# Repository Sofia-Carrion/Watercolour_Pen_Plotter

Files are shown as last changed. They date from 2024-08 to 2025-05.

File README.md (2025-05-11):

# Watercolour_Pen_Plotter
(WIP)

<p align="center">
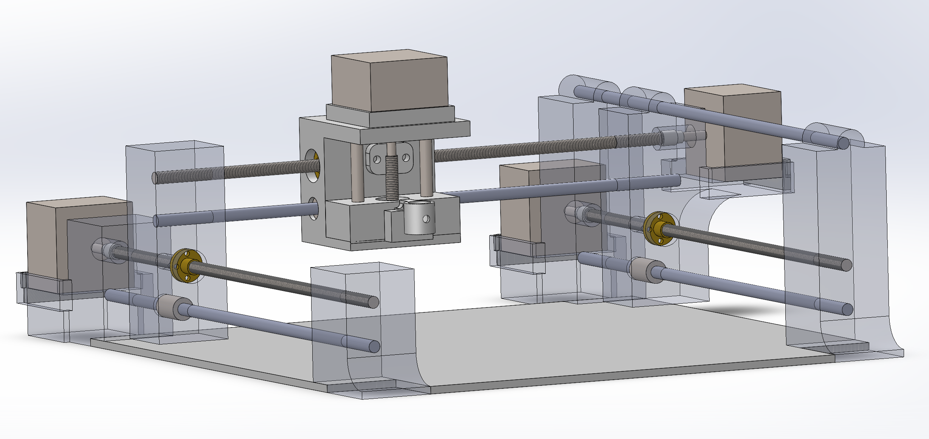
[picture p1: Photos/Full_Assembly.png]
Full Assembly
  
</p>

## About:
The Watercolour Pen Plotter is a CNC machine designed to operate like a traditional pen plotter but tailored for watercolor painting on traditional 8.5 x 11 paper. The goal is to create a compact, user-friendly frame with an added feature for mixing paint. The CNC machine will paint freely, blending colors and adjusting shades by varying the paint-to-water ratios through an automated process.

## Progress:
 [A detailed file describing the process can be found here](Progress.md)

Summary: 
_________________________________________________________________________________________________________________
Design:
- All components for the CNC machine have been brainstormed and designed. This was mainly done through sketches.
  
CAD:
- All CAD work has been completed for the chassis of the CNC machine on Solidworks. 

Electronics:
- Setup and tested scrap stepper motors that was found from an old machine by running G-code on CNC shield and Arduino Uno.

Prototyping:
- All custom parts have been printed and the chassis has been assmebled with the purchased metal parts.

Work to be complete:
- Running all electrical components with chassis: testing and debugging
- Research on how to manipulate G-code to preform painting
___________________________________________________________________________________________________________________

  The design process encompassed many sketches. A full PDF of my sketches can be found 
  [here](WCPP_Design.pdf)

## CAD Models:

All SolidWork CAD models were created using SolidWorks 2023. All files for the assembly can be found in the repository.

## External Help (Parts that will be put to use):

The following parts and links are pieces that I plan to use in this project. I used their dimensions to help create my CADs.

[Linear Ball Bearings](https://www.amazon.ca/Linear-Bearing-Bushing-Bearings-Printer/dp/B07G959TX9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 )

[Thread/Brass Nut](https://www.amazon.ca/150mm%EF%BC%885-9-Inches%EF%BC%89Tr8x2-Thread-Printer-Machine/dp/B08JLHSHQ7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)

[Metal Rods](https://www.amazon.ca/dp/B0BRKD43TP?ref=ppx_yo2ov_dt_b_fed_asin_title&th=1 )

Stepper Motors: (Not sure right now, they were scrap motors)

(Any other parts I will update as I move along)

  ## Looking to Help Out?

If you are interested in collaborating to make this project even bigger and cooler, don't hesitate to reach out! I'd love to work with others and get different insights and perspectives.

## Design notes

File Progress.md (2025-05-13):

# Current Progress

  ## WORK DONE FOR BASIC CHASSIS:
  ----------------------------------

  The project started off as a basic pen plotter. The following showcases the main steps I took to create a full SolidWorks assembly of its structure.

### 1. Movement:

  I began this project by planning the movement of the pen. Since the machine needed to draw, incorporating both the x and y axes was obvious. Likewise, adding a z-axis to lift and lower the pen onto the paper was essential. However, I needed to consider the displacement required for each axis. To keep things simple, I decided the machine should be capable of drawing anywhere on a standard 8.5 by 11-inch sheet of paper. For the z-axis, I chose a 1 cm range, which would provide enough clearance for brushes to create varying thicknesses if I decided to include that feature.
    
  With the basic concept established, I considered different ways to achieve movement. Having previous experience with CNC machines and having designed parts for one myself, I opted for a standard thread and nut, as my experience with these has been straightforward and reliable. Keeping this in mind, I started sketching how I envisioned the machine operating. An early-stage sketch can be seen below:

<p align="center">
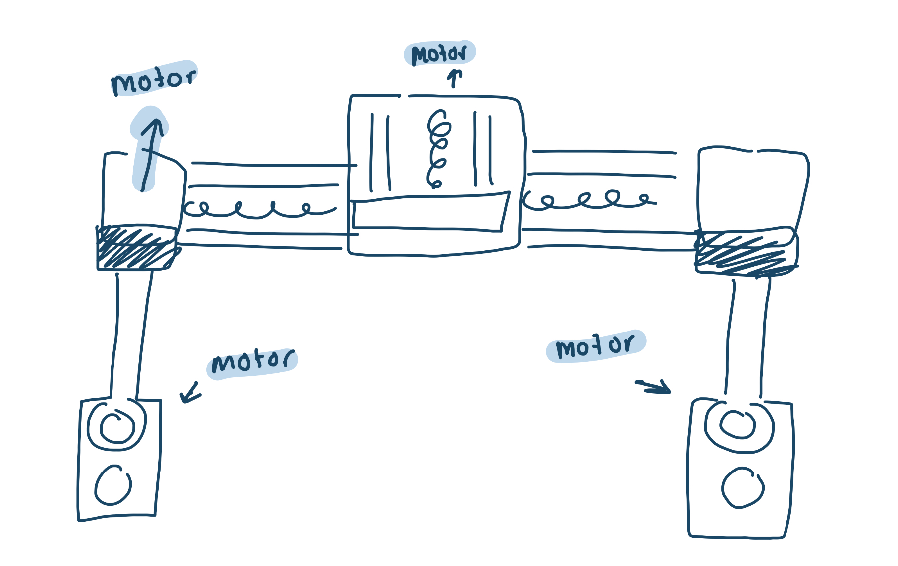
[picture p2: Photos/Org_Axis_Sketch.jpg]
Original Sketch
  
</p>

  Later on, I updated these sketches to be a bit more clear and showcase each axis individually:

<p align="center">
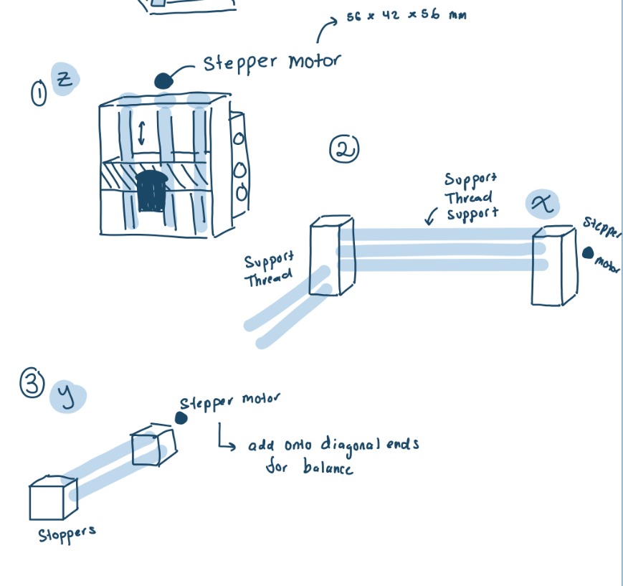
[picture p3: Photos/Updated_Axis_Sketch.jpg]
Updated Sketch
  
</p>

The general idea was that each axis would be controlled by 1-2 stepper motors, be moved through thread and nuts, and have two support beams to keep them in place. Additionally, linear ball bearings will be used where necessary to help facilitate movement.

### 2. Design of each axis:

  With a general idea of how I wanted the machine to operate, I began to do some work in CAD and assemble each of the axis individually. I played around with different sizes and shapes, aiming to make the machine as small as possible. The biggest change between the initial sketches and their new CADS was the removal of one of the support rods. This was done as I had found that everything was relatively light enough that one support rod could suffice (I did add an extra one for the right side of the y axis since the stepper motor would weight it down on one side). CADs of each assembly for the Z,X, and Y axis could be seen below:

<p align="center">
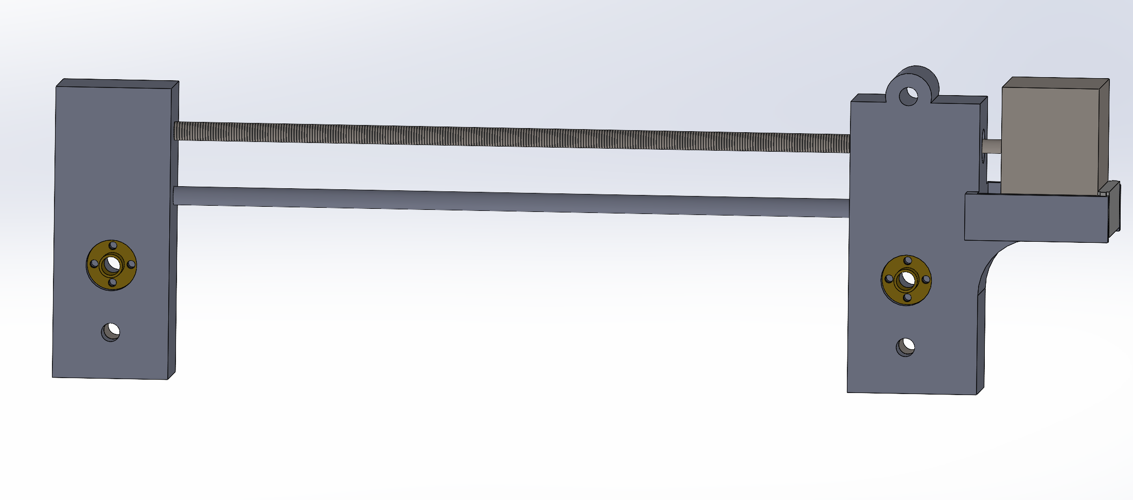
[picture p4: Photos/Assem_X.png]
CAD_x
  
</p>

<p align="center">
  Assembly of the X axis
</p>

<p align="center">
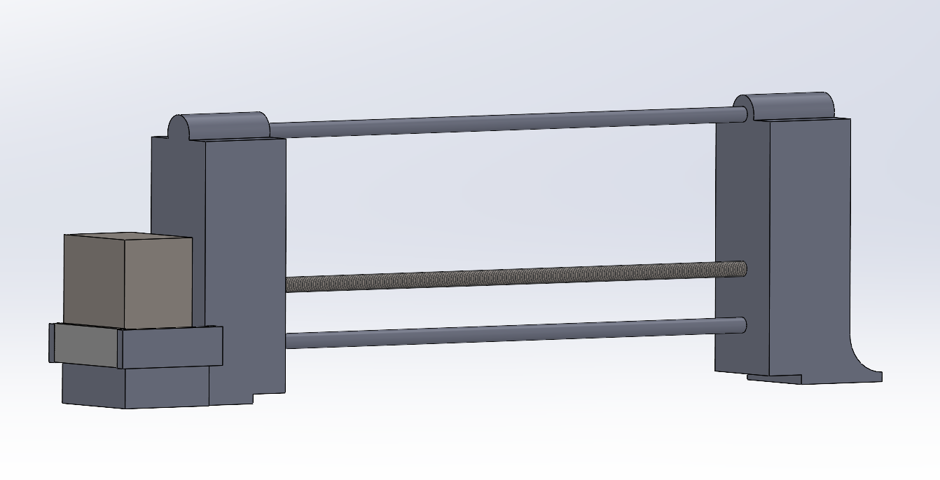
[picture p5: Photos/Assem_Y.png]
CAD_Y
  
</p>

<p align="center">
  Assembly of the Y axis (left side)
</p>

<p align="center">
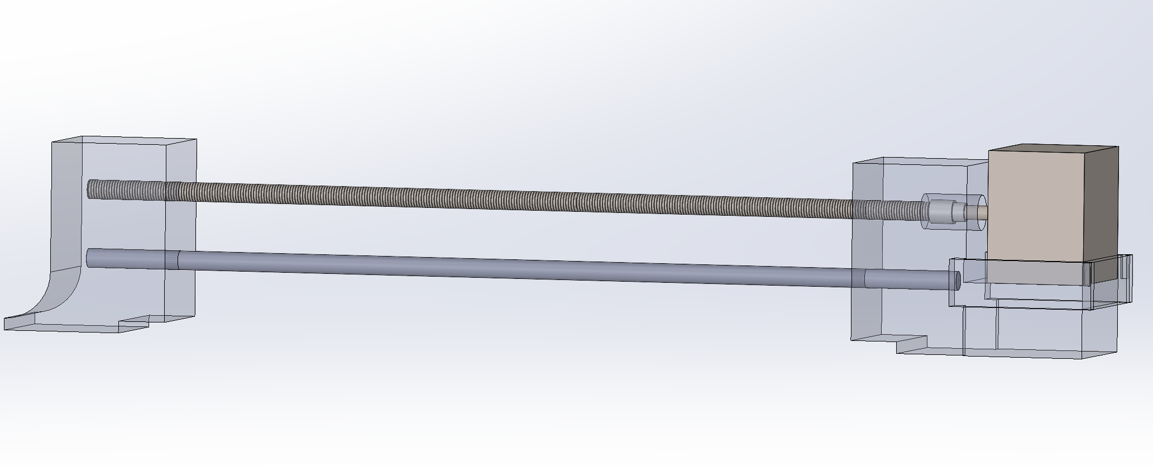
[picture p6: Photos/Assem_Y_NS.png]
CAD_Y_2
  
</p>

<p align="center">
  Assembly of the Y axis (Right side)
</p>

<p align="center">
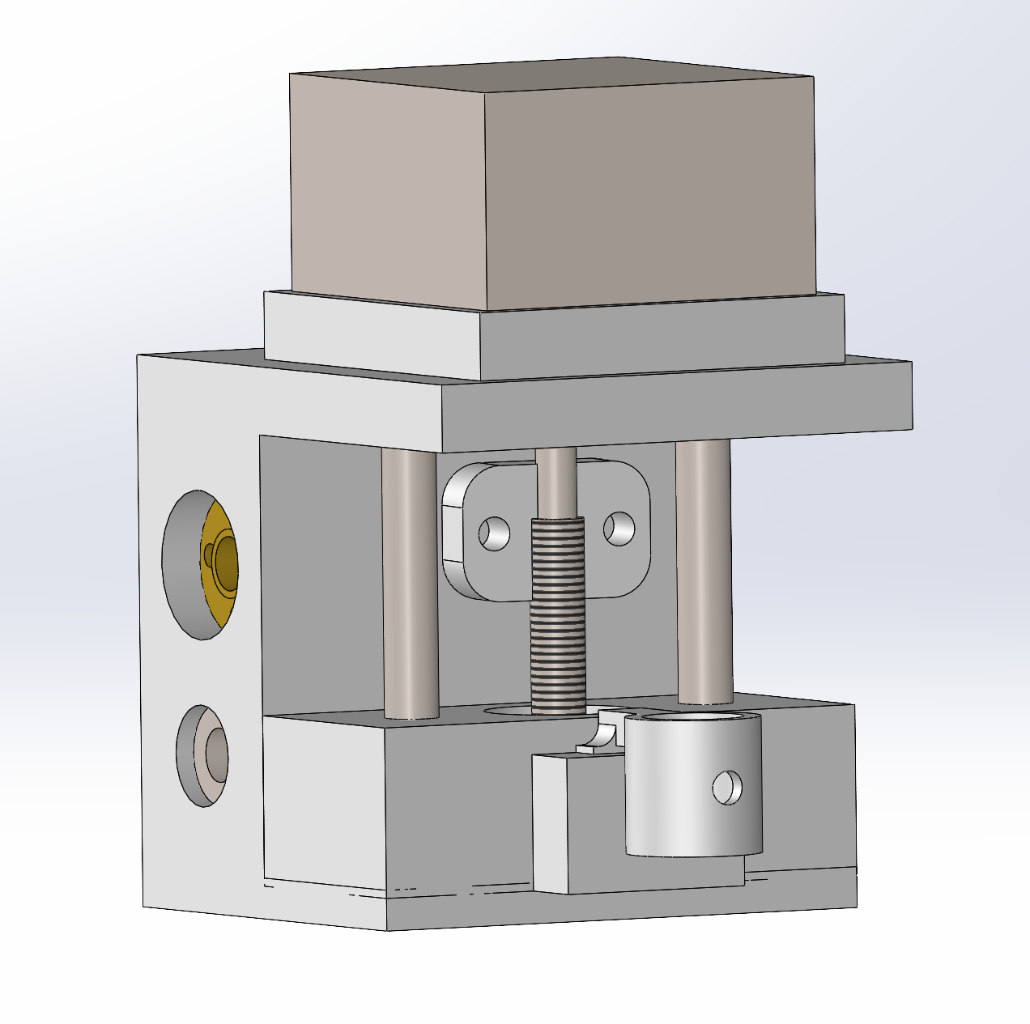
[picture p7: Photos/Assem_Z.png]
CAD_Z
  
</p>

<p align="center">
  Assembly of the Z axis (Note: The piece that connects the thread and shaft only shows half of it for visibility reasons)
</p>

### 3. Assmebly:

 Once I had each individual axis assembled, I began to piece it all together in one big assembly, making any necessary changes to ensure a proper fit. A close up of how each axis fit can be seen below:

<p align="center">
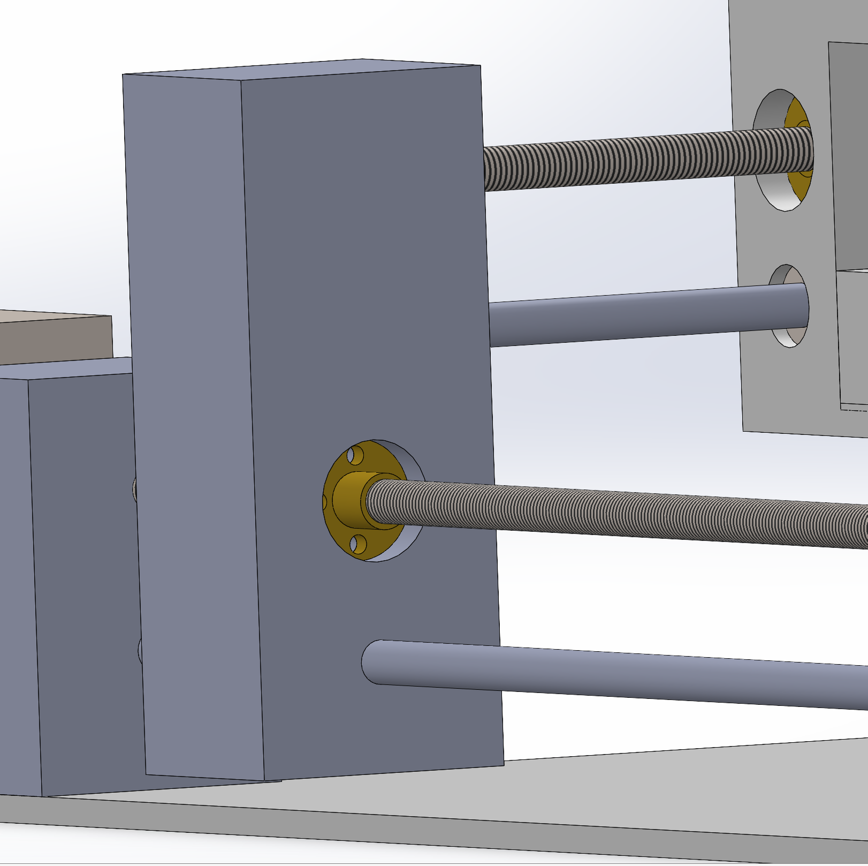
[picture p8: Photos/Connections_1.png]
Connections_1
  
</p>

<p align="center">
  Example image of how the axis connect with one another
</p>

<p align="center">
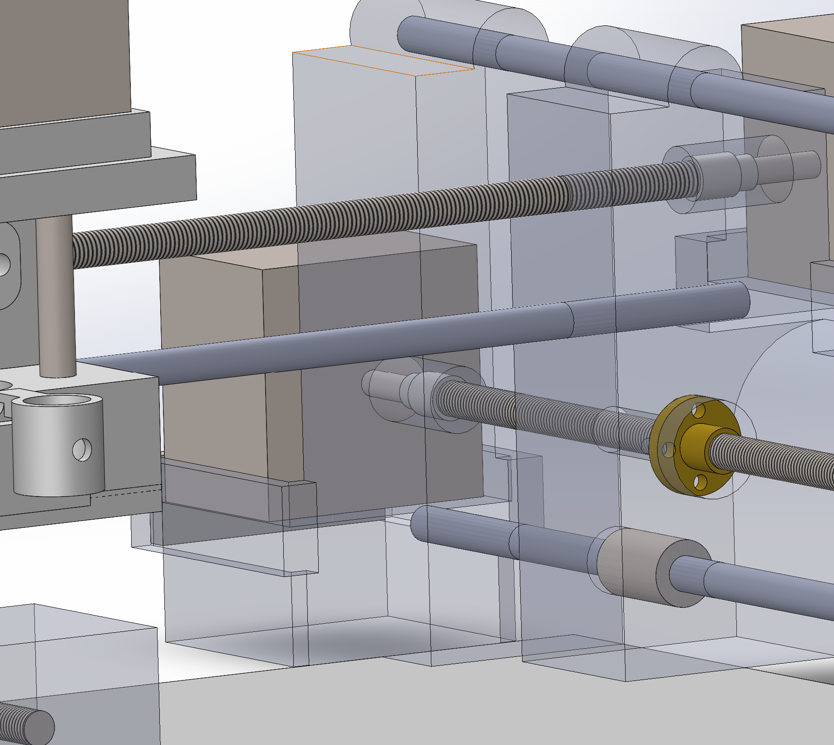
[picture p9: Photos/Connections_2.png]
Connections_2
  
</p>

<p align="center">
  Example image of how the axis connect with one another and the inside structure
</p>

Hopefully it's not too hard to see above, but for a quick explanation: The Z axis moves along the x axis which is being supported by two bases, both of which move alone the y axis. (This is more clear in the image of the full assembly below)

   Once it all fit smoothly, I did some calculations for how large to make the rods, threads, and the overall base of the structure (This did change later on when I decided to add the watercolour attachment). With the sizing determined, an assembly was created:

<p align="center">
  Connections_2
</p>

<p align="center">
  Full assembly of the basic chassis
</p>

<p align="center">
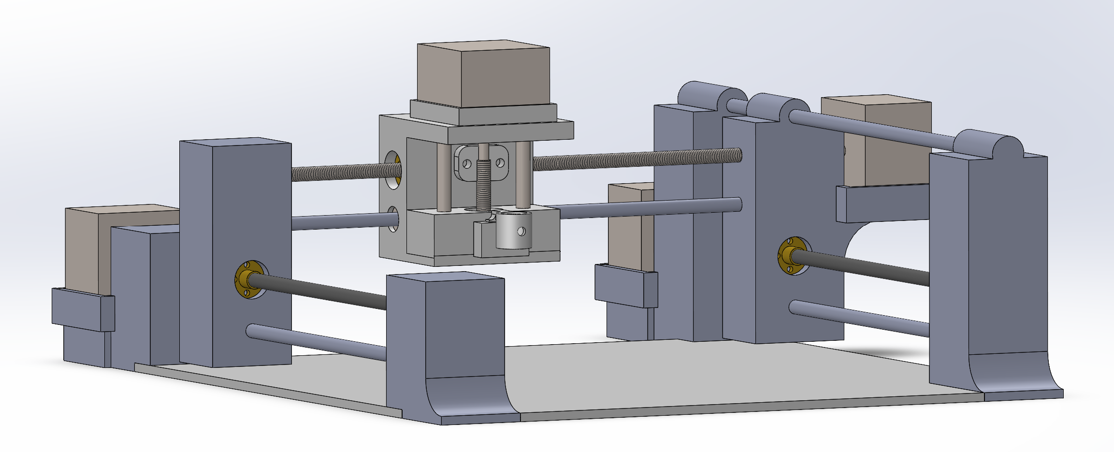
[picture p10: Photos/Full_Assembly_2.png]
  
</p>

<p align="center">
  Full assembly of the basic chassis with view of the inside structure
</p>

  ### 4. Attachments/Extra Features:

  Other parts had to be made as well in order to ensure everything fit nicely.

  For instance, I designed and modeled a holder for the stepper motors. I realized that with a normal box support, it would be very difficult to assemble the stepper motor with the thread and rod. For this reason, I added a little "gate" that allows you to freely slide the motor in and out. A sketch and its CAD can be seen below:

<p align="center">
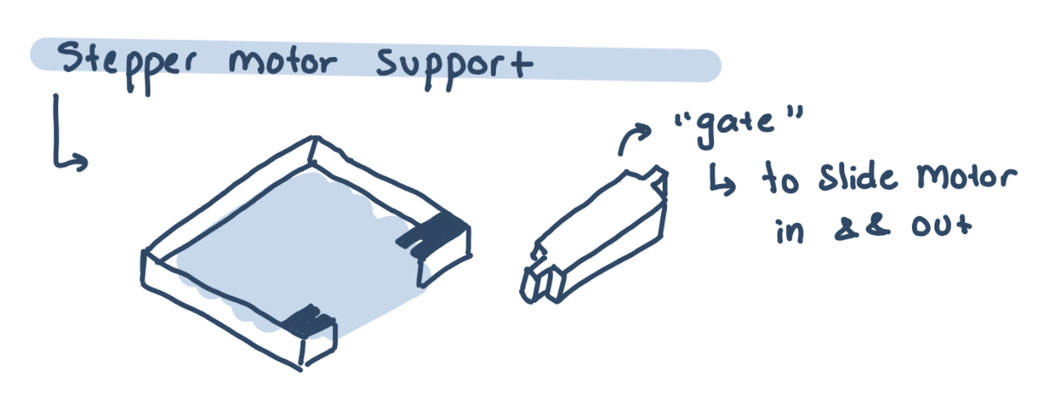
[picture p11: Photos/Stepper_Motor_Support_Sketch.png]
Stepper Motor Supp Sketch
  
</p>

<p align="center">
  Sketch of stepper motor support design
</p>

<p align="center">
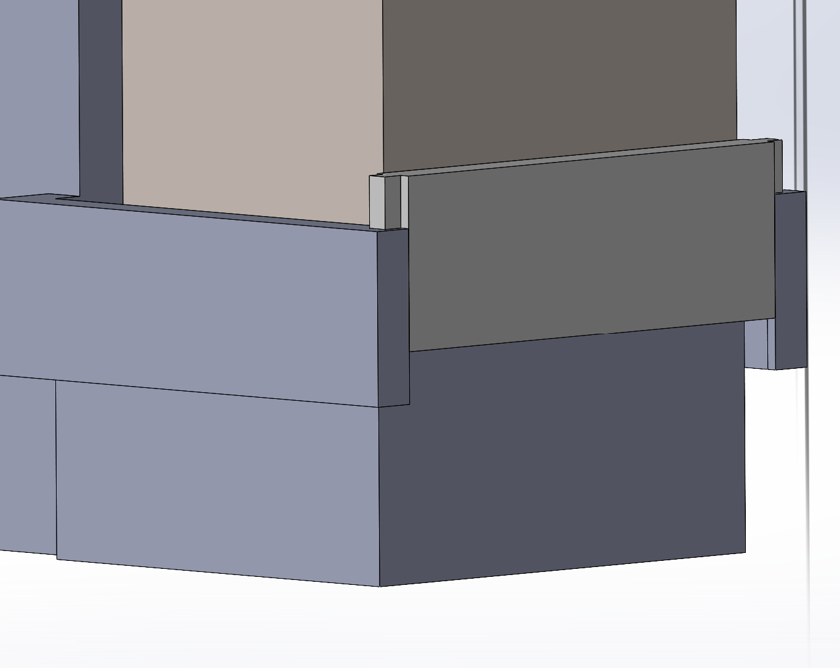
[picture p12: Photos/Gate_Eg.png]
Stepper Motor Supp
  
</p>

<p align="center">
  CAD of stepper motor support
</p>

I also had two different designs for a part that could hold the shaft of the motor to the threaded rod. Both designs and models can be seen below and both were incorporated into the final design:

<p align="center">
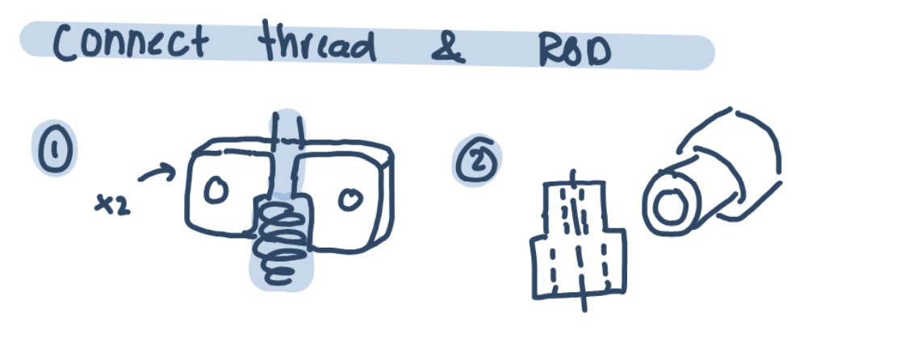
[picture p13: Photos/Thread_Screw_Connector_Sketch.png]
Connector Sketch
  
</p>

<p align="center">
  Sketches of both design ideas to connect motor shaft and thread
</p>

<p align="center">
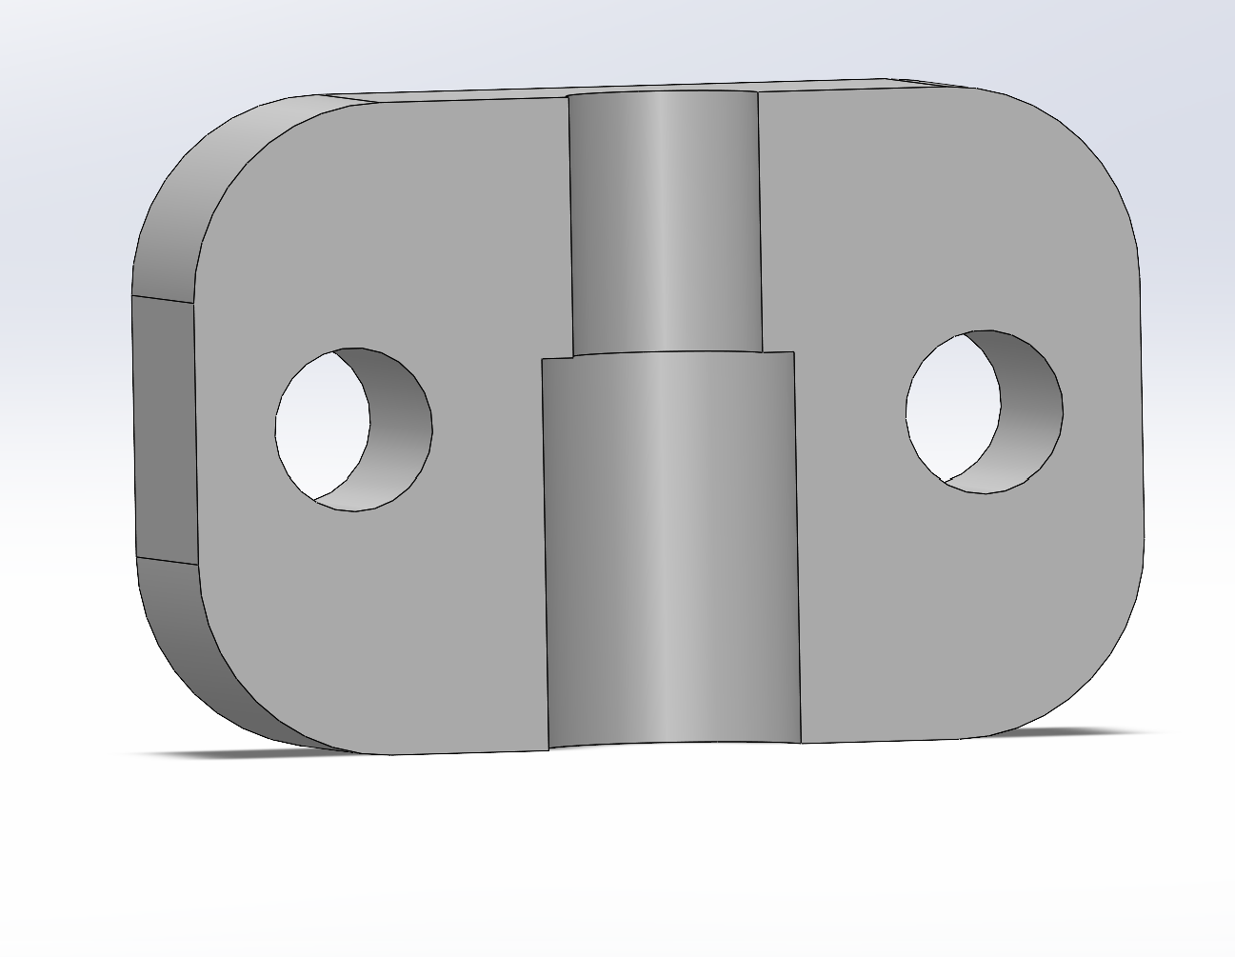
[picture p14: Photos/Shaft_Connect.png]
Connector 1
  
</p>

<p align="center">
  CAD of thread and shaft connector V1 (one half)
</p>

<p align="center">
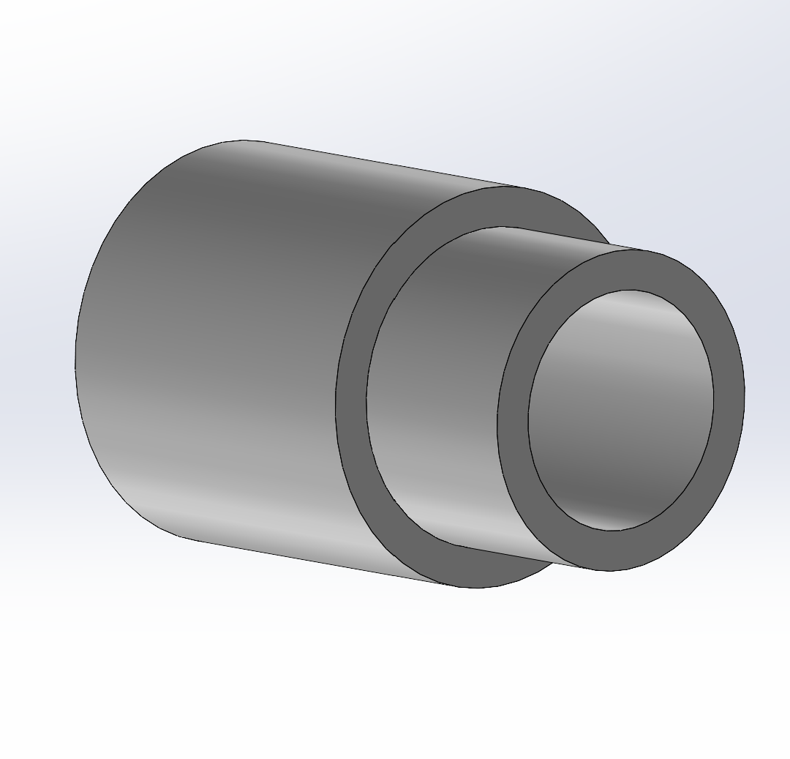
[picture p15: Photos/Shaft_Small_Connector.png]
Connector 2
  
</p>

<p align="center">
  CAD of thread and shaft connector V2
</p>

The final attachment was a simple design to hold the pen/brush in place. Inspired by a compass, this attachement useses a screw and thread to tighten and hold it:

<p align="center">
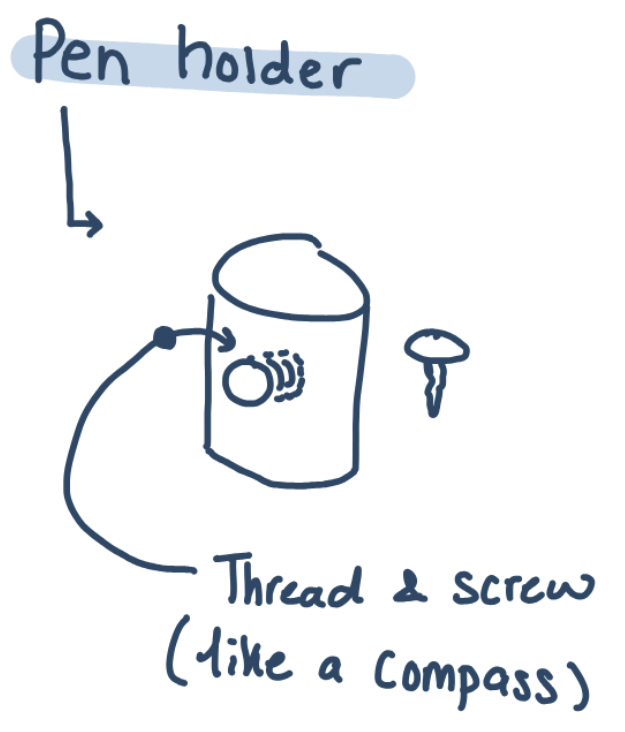
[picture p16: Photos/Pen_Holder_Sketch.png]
Pen holder sketch
  
</p>

<p align="center">
  Sketch of pen holder design
</p>

<p align="center">
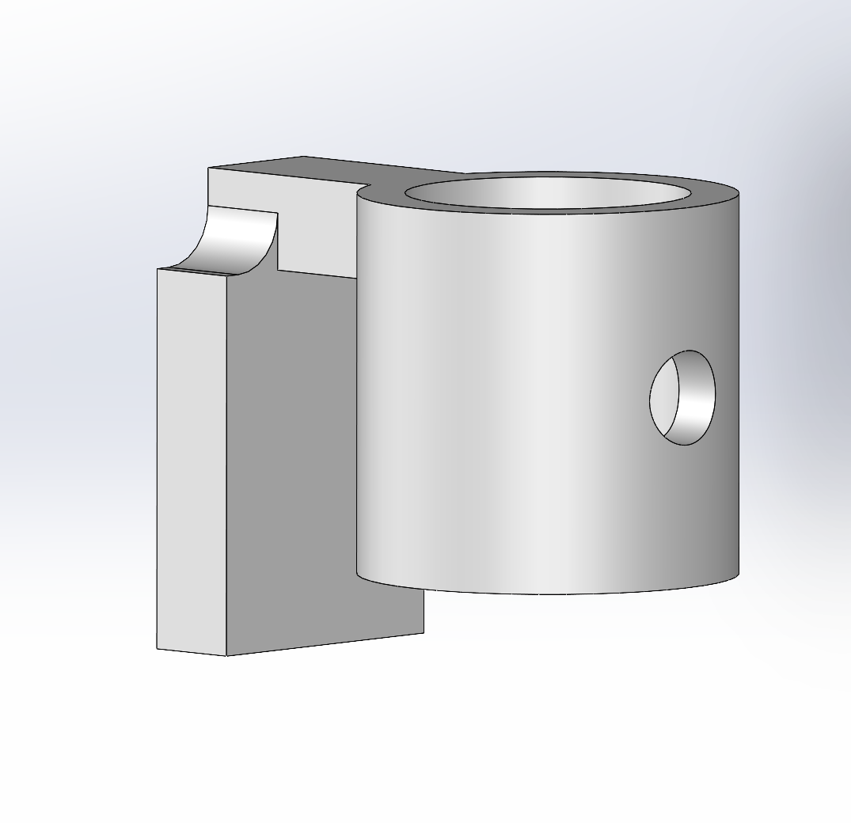
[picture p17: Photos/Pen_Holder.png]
Pen holder
  
</p>

<p align="center">
  CAD of pen holder
</p>

## WORK DONE FOR THE WATERCOLOUR COMPONENT:
------------------------------------------------

To add depth and more complexity to this project, I decided to challenge myself to make the Pen Plotter be able to mix colours and shades through the use of water colours. Below the current work I have done to acheive this can be found:

### 1. Necessary Components:

   I began by brainstorming what components may be needed for a machine to be able to freely use water colours. I thought back to my watercolouring days and noted that varying paints, clean water, and tissue paper was necessary in order to have untainted colours of varying shades while painting. An initial sketch of how these elements could be incoportaed are found below:

<p align="center">
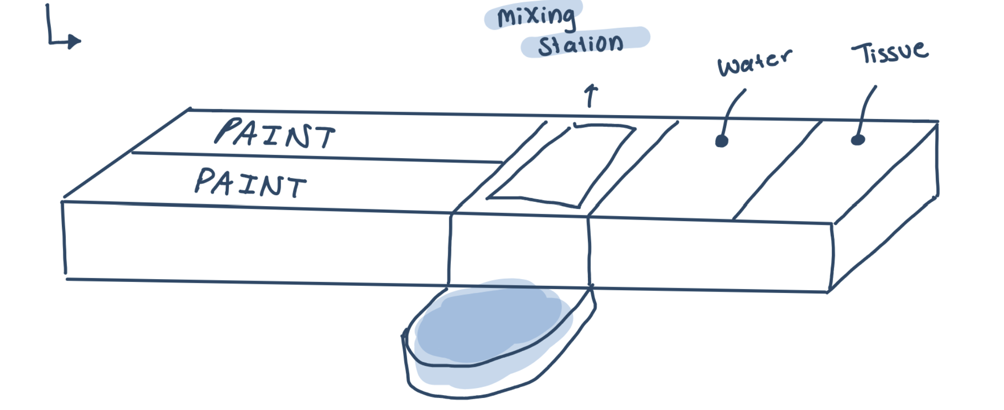
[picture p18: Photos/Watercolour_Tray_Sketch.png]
Tray Sketch
  
</p>

From here, I realized one big issue. Unless there was human interferance with the machine as it operated, the water used to mix the watercolours would be murky and not allow the colours to mix nicely. A solution to this? A flushing system. 

### 2. Flushing System:

   I took inspiration from other flushing systems I have seen for watercolouring. They often looked something like this:

<p align="center">
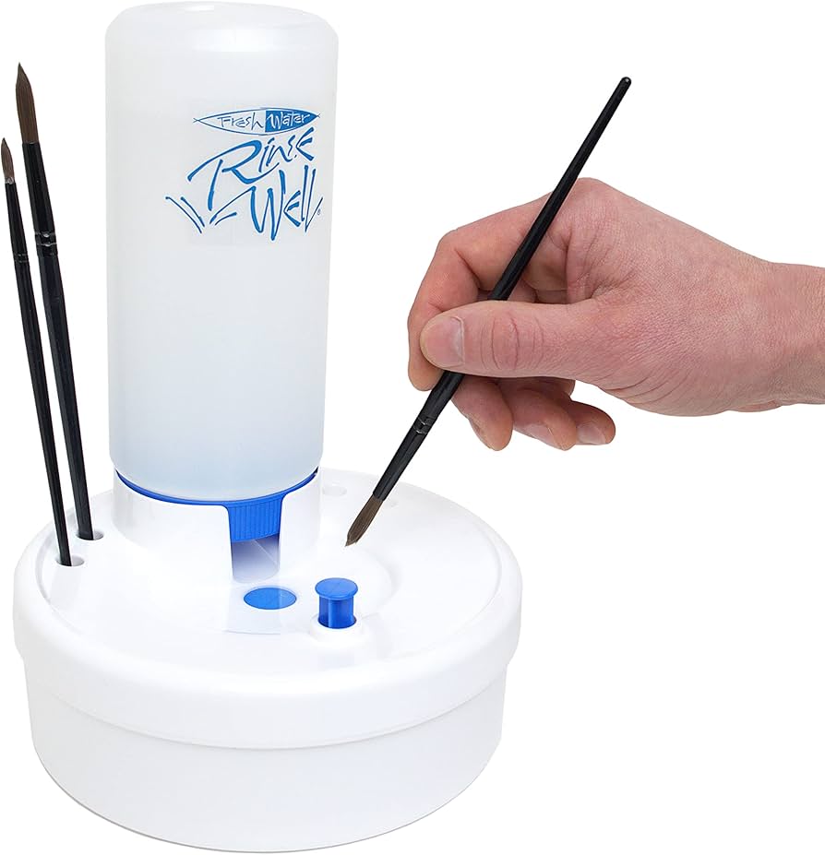
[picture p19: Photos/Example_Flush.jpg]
Inspiration Flushing System
  
</p>

 I simplified the design of this product and sketched and CADed my own miniature version that can hopefully be used in the machine. Some work still has to be done on it, but the general idea and early stage CAD can be seen below: 

<p align="center">
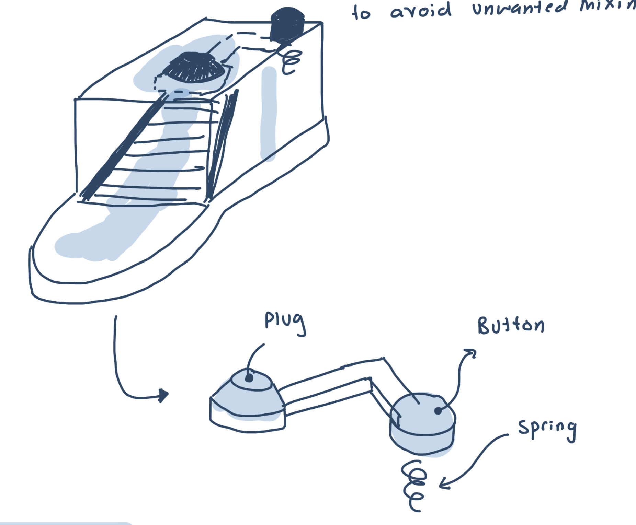
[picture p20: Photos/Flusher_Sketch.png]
Flushing System Sketch
  
</p>

<p align="center">
  Sketch of flushing system
</p>

<p align="center">
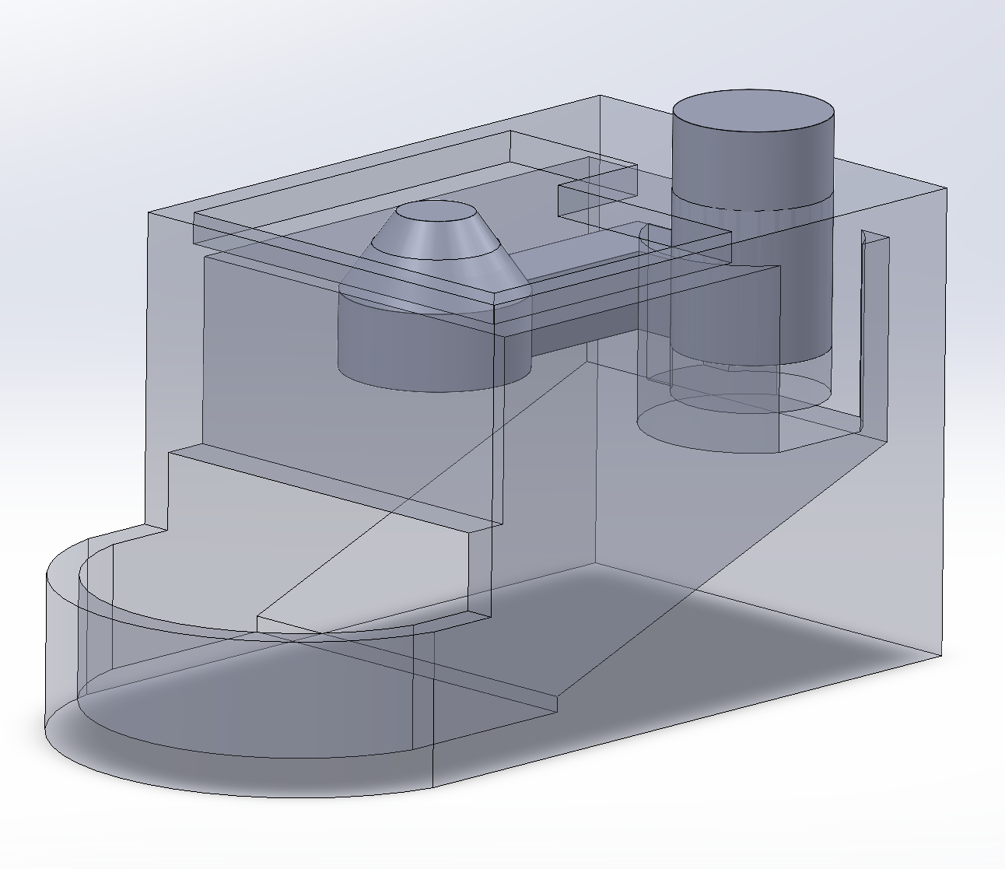
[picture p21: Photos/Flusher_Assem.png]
Flusher CAD
  
</p>

<p align="center">
  CAD of flushing system
</p>

### 3. Prototyping and Assembly of Tray

   (wip)

### 4. Prototyping and Assembly of entire CNC chassis:

   Currently, I have done rapid prototyping of all the custom parts that I created in SolidWorks. Since this was a very quick and rough prototype, I used lightning for the infill geometry at 15%. This infill is very weak and will not be used for the final prototype. Photos of the parts in an assembled chassis can be seen below.

   <p align="center">
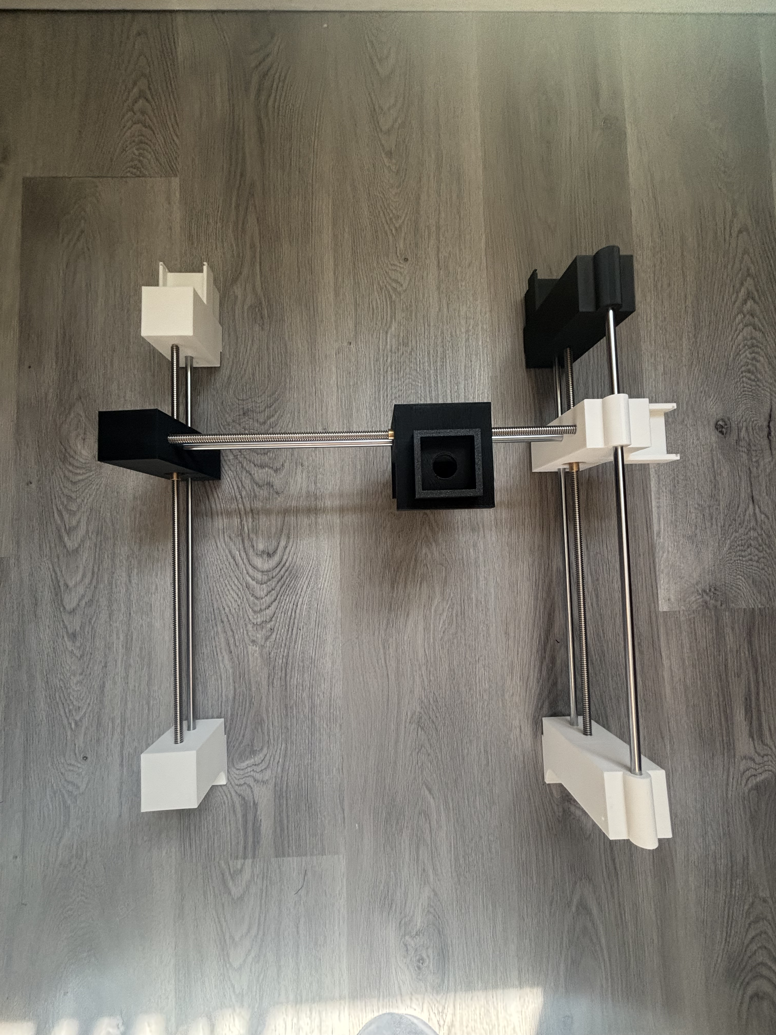
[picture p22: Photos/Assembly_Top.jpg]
Assembly Top View
      
    </p>

  <p align="center">
      Full Assembly
  </p>

  <p align="center">
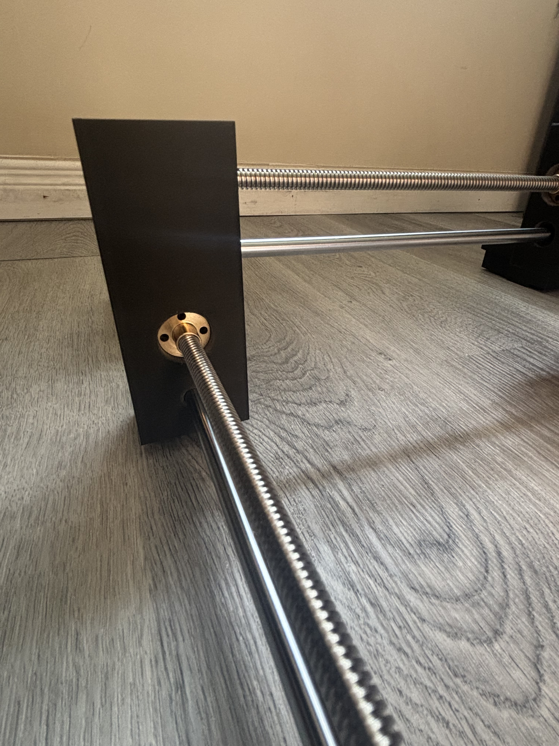
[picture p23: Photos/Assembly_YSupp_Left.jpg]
      
    </p>

  <p align="center">
      Y Support (Left)
  </p>

  <p align="center">
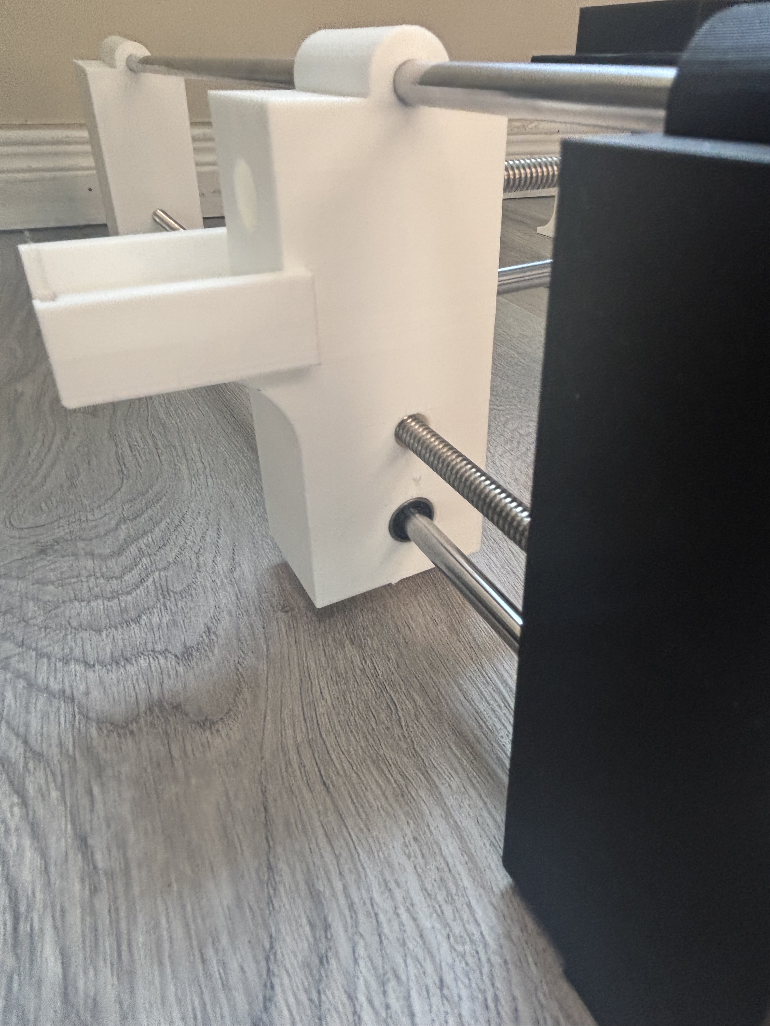
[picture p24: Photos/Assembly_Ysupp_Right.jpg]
      
    </p>

  <p align="center">
      Y Support (Right)
  </p>

  <p align="center">
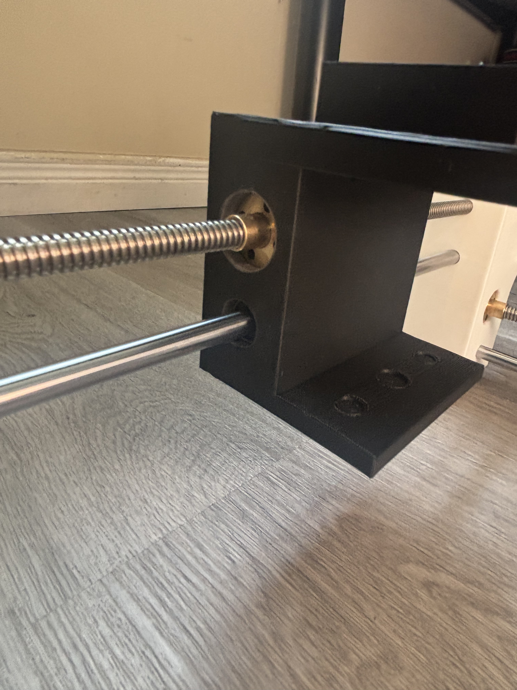
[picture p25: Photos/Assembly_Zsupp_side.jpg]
      
    </p>

  <p align="center">
      Z Support
  </p>
  
  <p align="center">
      
    </p>

  <p align="center">
      Y Support (Right)
  </p>

  <p align="center">
      
    </p>

  <p align="center">
      Flusher System
  </p>

  <p align="center">
      
    </p>

  <p align="center">
      Z Axis
  </p>

  <p align="center">
      
    </p>

  <p align="center">
     Z Block
  </p>

  A better and stronger prototype is currently in the works and photos will be uploaded once assembled and complete.

## WORK DONE FOR ELECTRICAL COMPONENT:
-----------------------------------------

For the electronics, I verified stepper motor wiring by checking coil continuity in unconventional motor leads to ensure correct connections. I successfully ran G-code using a CNC shield and Arduino Uno to achieve precise motor control, and have begun researching G-code manipulation to adapt motion paths for watercolor painting behavior.

 ## NOTES:
 ----------------
The addition of the watercolour component is still a WIP. This Progress page will be continuously updated as more work is done. Stay tuned!

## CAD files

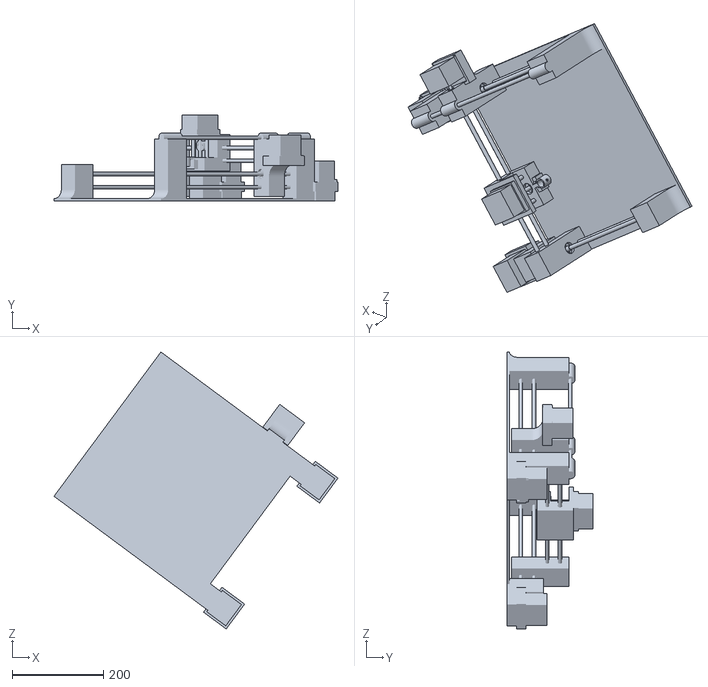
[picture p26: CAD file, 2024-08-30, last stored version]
CAD/FULL_ASSEMBLY.STL
623.2 x 188.0 x 607.8
